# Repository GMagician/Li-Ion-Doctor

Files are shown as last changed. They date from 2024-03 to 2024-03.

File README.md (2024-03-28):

# Lithium battery doctor

**PROOF OF CONCEPT PROJECT**

**:warning::boom: WARNING:LITHIUM BATTERY MAY EASILY EXPLODE OR TAKE FIRE, REPLICATE THIS PROJECT AT YOUR OWN RISK:boom::warning:**

Complete solution for Li Ion batteries

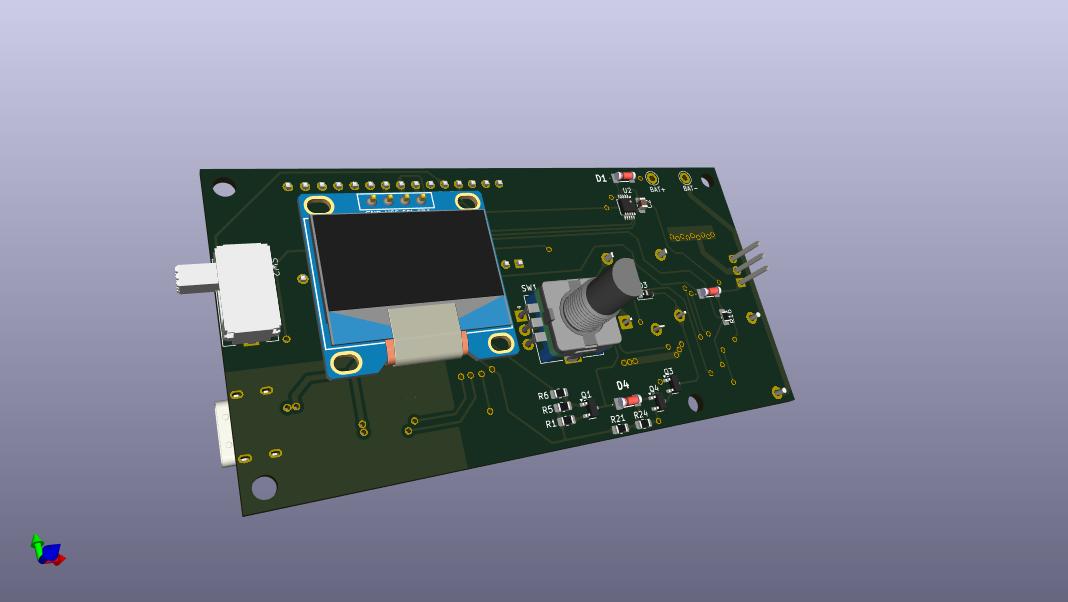
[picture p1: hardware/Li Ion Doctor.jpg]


Features:<br />
  Charge, discharge, amp hours count, test for short or open circuit, weak battery indicator, measure internal resistance.

- Charge:<br />
  TP4056 module (integrated), selectable current ~200/500/1000mA. TP4056 circuit is monitored by Arduino.
- Discharge:<br />
  current up to 2000mA (step 10mA), PWM controlled. Internal resistance is calculated from battery voltage drop under load.
- Capacity:<br />
  Battery gets fully charged, then discharged, mAh on selected current load is counted.
- Recovery:<br />
  Deep discharged battery charge with 100mA current.<br /><br />

This is a revisited project originally developped by Akos Boda in 2022 (https://www.thingiverse.com/thing:5229303).

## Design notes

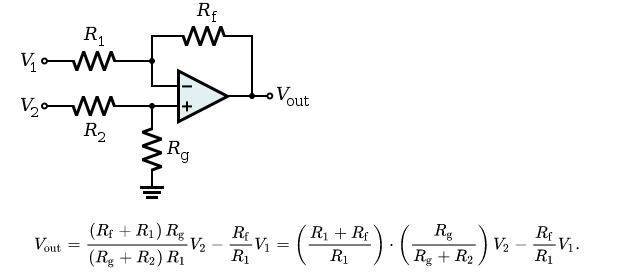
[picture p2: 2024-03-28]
hardware/documents/Differential amplifier + offset.png

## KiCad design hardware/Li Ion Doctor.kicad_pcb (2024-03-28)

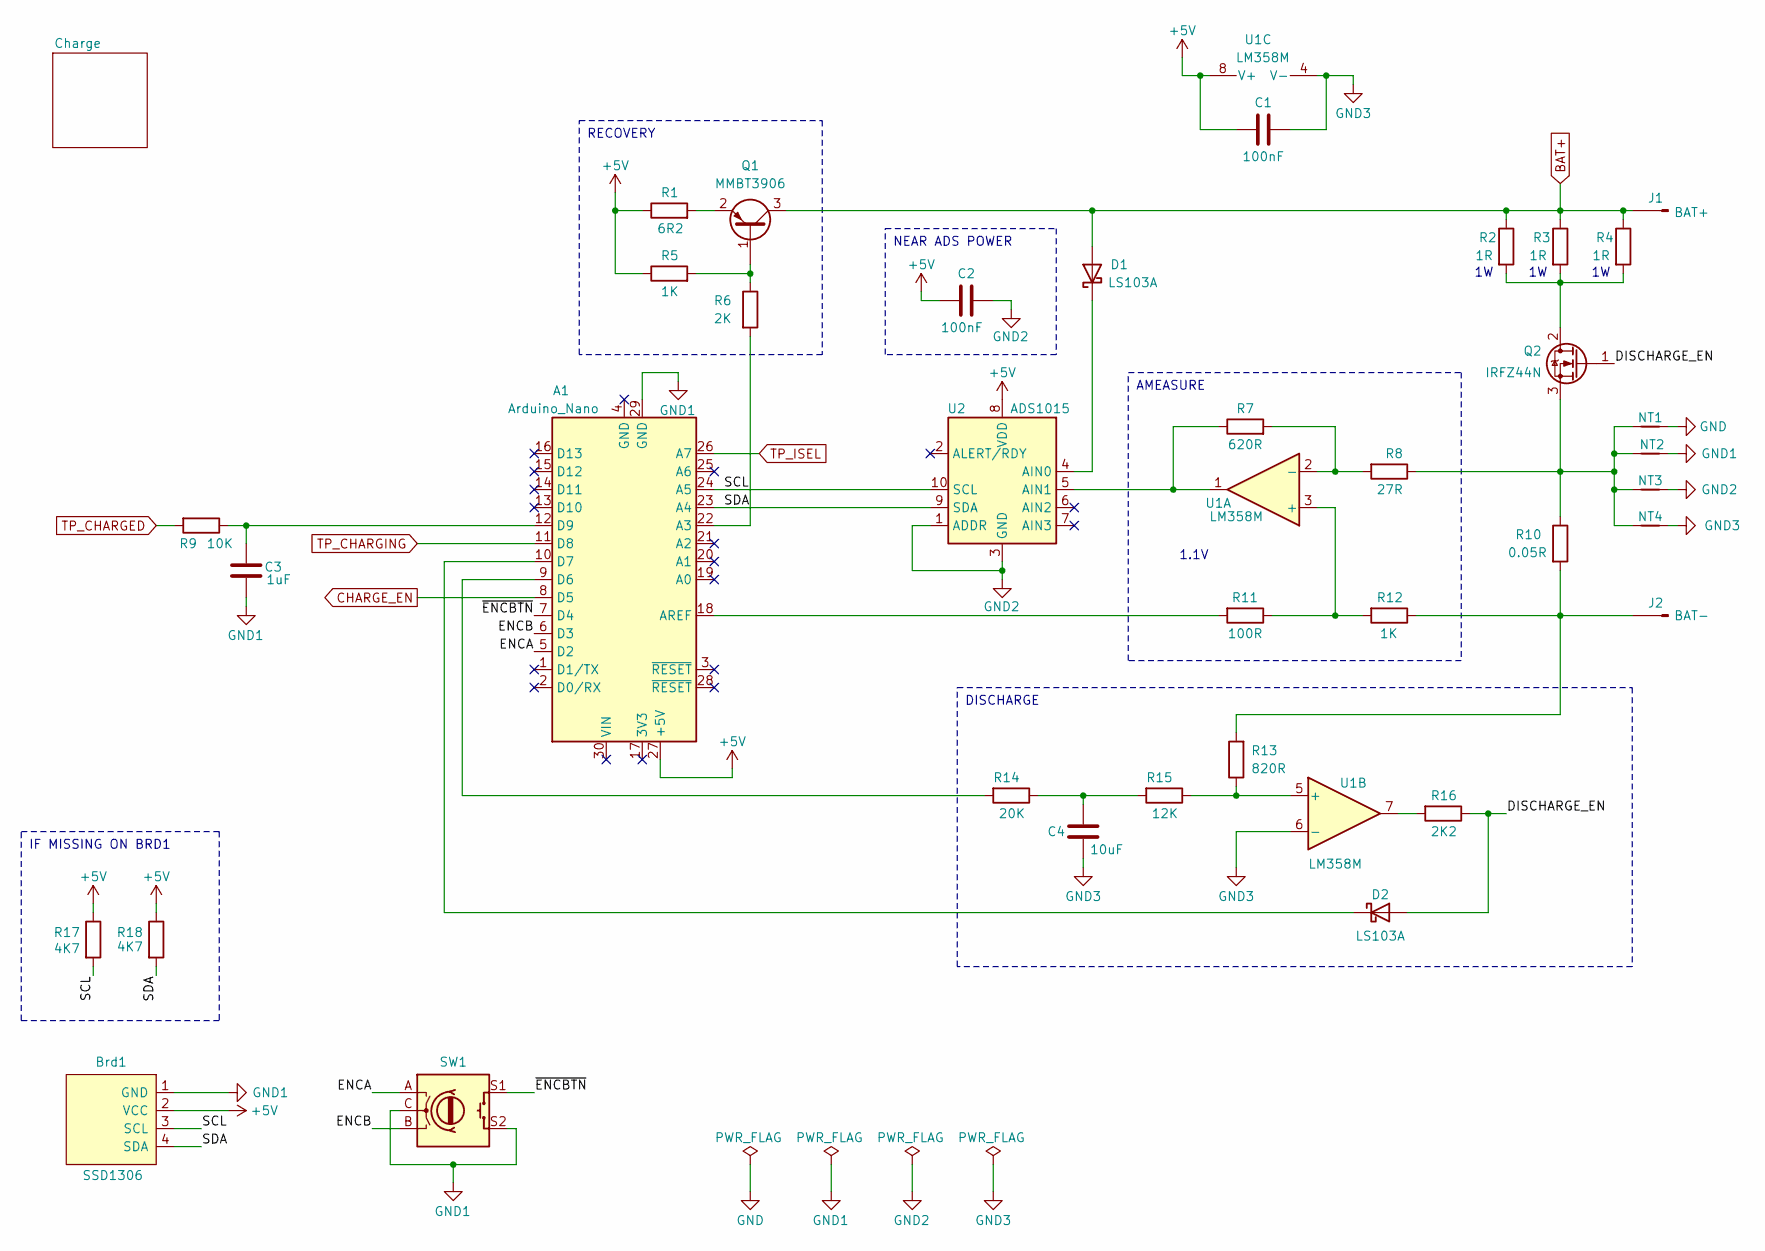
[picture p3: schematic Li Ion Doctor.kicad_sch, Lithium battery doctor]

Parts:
A1: Arduino_Nano
Brd1: SSD1306; SSD1306_OLED_DISPLAY_0.96
C1, C2: 100nF; C_0805_2012Metric_Pad1.18x1.45mm_HandSolder
C3: 1uF; C_0805_2012Metric_Pad1.18x1.45mm_HandSolder
C4: 10uF; C_0805_2012Metric_Pad1.18x1.45mm_HandSolder
D1, D2: LS103A; D_SOD-80
J1: BAT+; Pin_D1.0mm_L10.0mm_LooseFit
J2: BAT-; Pin_D1.0mm_L10.0mm_LooseFit
NT1: NetTie_2; NetTie-2_SMD_Pad2.0mm
NT2, NT3, NT4: NetTie_2; NetTie-2_SMD_Pad0.5mm
Q1: MMBT3906; SOT-23
Q2: IRFZ44N; TO-220-3_Vertical
R1: 6R2; R_0805_2012Metric_Pad1.20x1.40mm_HandSolder
R2, R3, R4: 1R; R_2512_6332Metric_Pad1.40x3.35mm_HandSolder
R5, R12: 1K; R_0805_2012Metric_Pad1.20x1.40mm_HandSolder
R6: 2K; R_0805_2012Metric_Pad1.20x1.40mm_HandSolder
R7: 620R; R_0805_2012Metric_Pad1.20x1.40mm_HandSolder
R8: 27R; R_0805_2012Metric_Pad1.20x1.40mm_HandSolder
R9: 10K; R_0805_2012Metric_Pad1.20x1.40mm_HandSolder
R10: 0.05R; R_Bare_Metal_Element_L18mm_W2.5mm_P15mm
R11: 100R; R_0805_2012Metric_Pad1.20x1.40mm_HandSolder
R13: 820R; R_0805_2012Metric_Pad1.20x1.40mm_HandSolder
R14: 20K; R_0805_2012Metric_Pad1.20x1.40mm_HandSolder
R15: 12K; R_0805_2012Metric_Pad1.20x1.40mm_HandSolder
R16: 2K2; R_0805_2012Metric_Pad1.20x1.40mm_HandSolder
R17, R18: 4K7; R_0805_2012Metric_Pad1.20x1.40mm_HandSolder
SW1: RotaryEncoder_Switch; RotaryEncoder-Switch_Vertical_H15mm
U1: LM358M; SOP-8_3.9x4.9mm_P1.27mm
U2: ADS1015; TSSOP-10_3x3mm_P0.5mm

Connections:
+5V: A1.27 (+5V), Brd1.2 (VCC), C1.1, C2.1, R1.1, R5.1, R17.1, R18.1, U1.8 (V+), U2.8 (VDD); also elsewhere on the board
/DISCHARGE_EN: D2.2 (A), Q2.1 (G), R16.1
/ENCA: A1.5 (D2), SW1.A
/ENCB: A1.6 (D3), SW1.B
/SCL: A1.24 (A5), Brd1.3 (SCL), R17.2, U2.10 (SCL)
/SDA: A1.23 (A4), Brd1.4 (SDA), R18.2, U2.9 (SDA)
/~ENCBTN: A1.7 (D4), SW1.S1
BAT+: D1.2 (A), J1.1, Q1.3 (C), R2.1, R3.1, R4.1; also elsewhere on the board
CHARGE_EN: A1.8 (D5); also elsewhere on the board
GND: NT1.1; also elsewhere on the board
GND1: A1.29 (GND), Brd1.1 (GND), C3.1, NT2.1, SW1.C, SW1.S2; also elsewhere on the board
GND2: C2.2, NT3.1, U2.1 (ADDR), U2.3 (GND)
GND3: C1.2, C4.2, NT4.1, U1.4 (V-), U1.6 (-)
unnamed: A1.22 (A3), R6.2
unnamed: A1.18 (AREF), R11.2
unnamed: A1.9 (D6), R14.2
unnamed: A1.10 (D7), D2.1 (K)
unnamed: A1.12 (D9), C3.2, R9.1
unnamed: C4.1, R14.1, R15.2
unnamed: D1.1 (K), U2.4 (AIN0)
unnamed: J2.1, R10.2, R12.1, R13.2
unnamed: Q1.1 (B), R5.2, R6.1
unnamed: Q1.2 (E), R1.2
unnamed: Q2.2 (D), R2.2, R3.2, R4.2
unnamed: NT1.2, NT2.2, NT3.2, NT4.2, Q2.3 (S), R8.1, R10.1
unnamed: R16.2, U1.7
unnamed: R11.1, R12.2, U1.3 (+)
unnamed: R7.2, R8.2, U1.2 (-)
unnamed: R13.1, R15.1, U1.5 (+)
unnamed: R7.1, U1.1, U2.5 (AIN1)
TP_CHARGED: R9.2; also elsewhere on the board
TP_CHARGING: A1.11 (D8); also elsewhere on the board
TP_ISEL: A1.26 (A7); also elsewhere on the board

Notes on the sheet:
DISCHARGE
RECOVERY
NEAR ADS POWER
AMEASURE
IF MISSING ON BRD1
1.1V

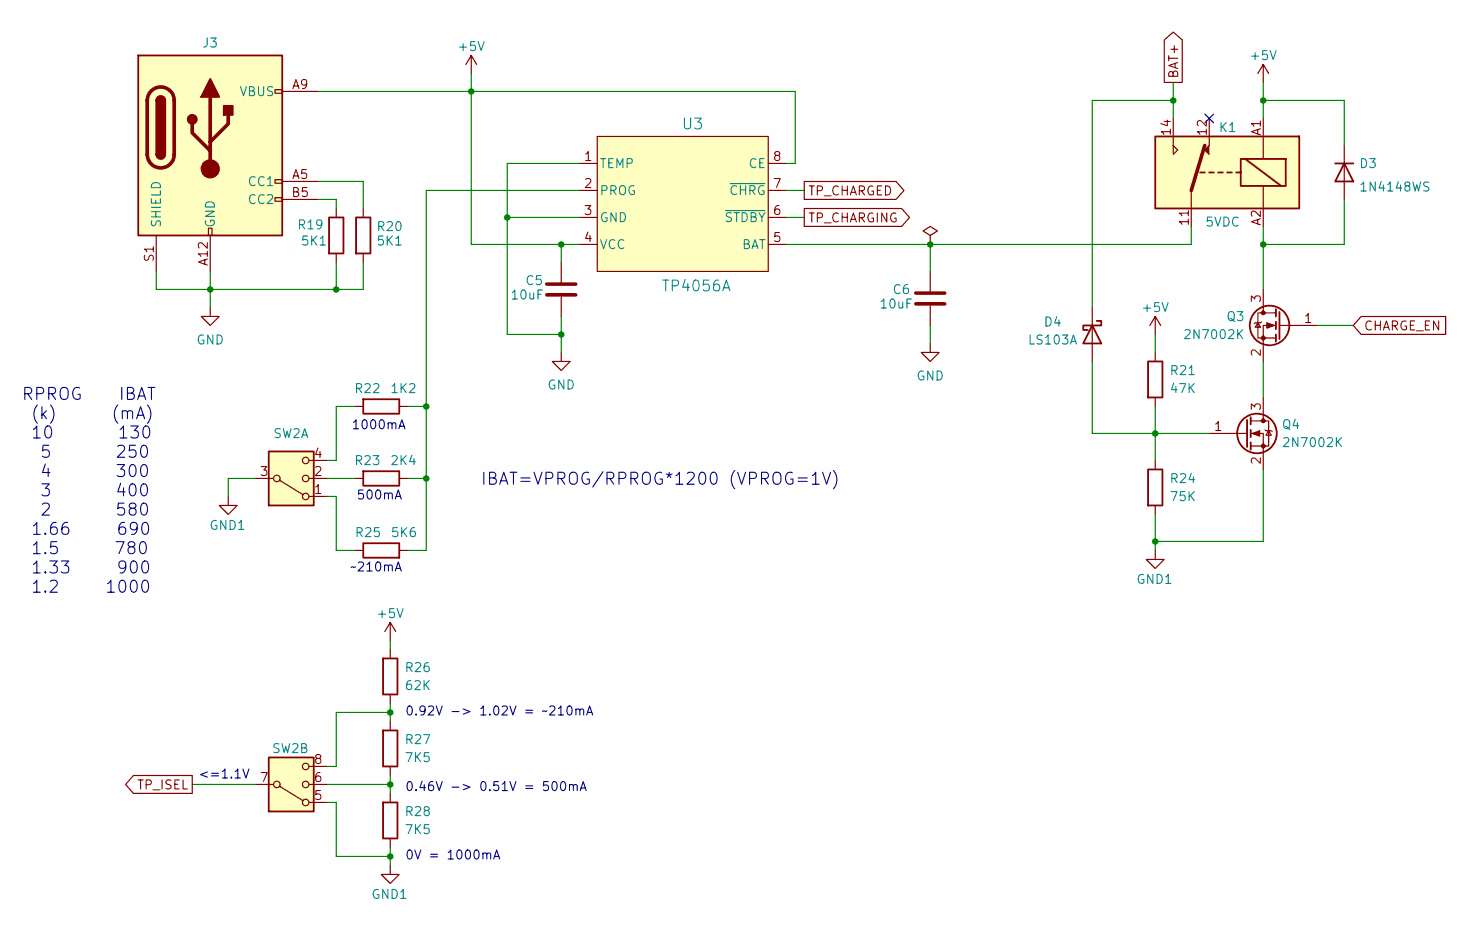
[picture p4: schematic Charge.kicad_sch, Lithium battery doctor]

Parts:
C5, C6: 10uF; C_0805_2012Metric_Pad1.18x1.45mm_HandSolder
D3: 1N4148WS; D_SOD-323_HandSoldering
D4: LS103A; D_SOD-80
J3: USB_C_Receptacle_PowerOnly_6P; USB_C_Receptacle_GCT_USB4125-xx-x_6P_TopMnt_Horizontal
K1: 5VDC; Relay_SPDT_Finder_36.11
Q3, Q4: 2N7002K; SOT-23
R19, R20: 5K1; R_0805_2012Metric_Pad1.20x1.40mm_HandSolder
R21: 47K; R_0805_2012Metric_Pad1.20x1.40mm_HandSolder
R22: 1K2; R_0805_2012Metric_Pad1.20x1.40mm_HandSolder
R23: 2K4; R_0805_2012Metric_Pad1.20x1.40mm_HandSolder
R24: 75K; R_0805_2012Metric_Pad1.20x1.40mm_HandSolder
R25: 5K6; R_0805_2012Metric_Pad1.20x1.40mm_HandSolder
R26: 62K; R_0805_2012Metric_Pad1.20x1.40mm_HandSolder
R27, R28: 7K5; R_0805_2012Metric_Pad1.20x1.40mm_HandSolder
SW2: SW_DP3T; SK23D07VG5
U3: TP4056A; SOP-8_4.2x5.3mm_P1.27mm_EP2.5x3.4mm_ThermalVias

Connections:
+5V: C5.1, D3.1 (K), J3.A9 (VBUS), J3.B9 (VBUS), K1.A1, R21.1, R26.2, U3.4 (VCC), U3.8 (CE); also elsewhere on the board
BAT+: D4.1 (K), K1.14; also elsewhere on the board
CHARGE_EN: Q3.1 (G); also elsewhere on the board
GND: C5.2, C6.1, J3.A12 (GND), J3.B12 (GND), J3.S1 (SHIELD), R19.2, R20.2, U3.1 (TEMP), U3.3 (GND), U3.9 (GND); also elsewhere on the board
GND1: Q4.2 (S), R24.2, R28.1, SW2.3, SW2.5; also elsewhere on the board
unnamed: D3.2 (A), K1.A2, Q3.3 (D)
unnamed: D4.2 (A), Q4.1 (G), R21.2, R24.1
unnamed: J3.A5 (CC1), R20.1
unnamed: J3.B5 (CC2), R19.1
unnamed: Q3.2 (S), Q4.3 (D)
unnamed: R22.2, SW2.4
unnamed: R23.2, SW2.2
unnamed: R25.1, SW2.1
unnamed: R26.1, R27.2, SW2.8
unnamed: R27.1, R28.2, SW2.6
unnamed: C6.2, K1.11, U3.5 (BAT)
unnamed: R22.1, R23.1, R25.2, U3.2 (PROG)
TP_CHARGED: U3.7 (~CHRG); also elsewhere on the board
TP_CHARGING: U3.6 (~STDBY); also elsewhere on the board
TP_ISEL: SW2.7; also elsewhere on the board

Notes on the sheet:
IBAT=VPROG/RPROG*1200 (VPROG=1V)
<=1.1V
500mA
RPROG IBAT (k) (mA) 10 130 5 250 4 300 3 400 2 580 1.66 690 1.5 780 1.33 900 1.2 1000
0.46V -> 0.51V = 500mA
0.92V -> 1.02V = ~210mA
~210mA
0V = 1000mA
1000mA

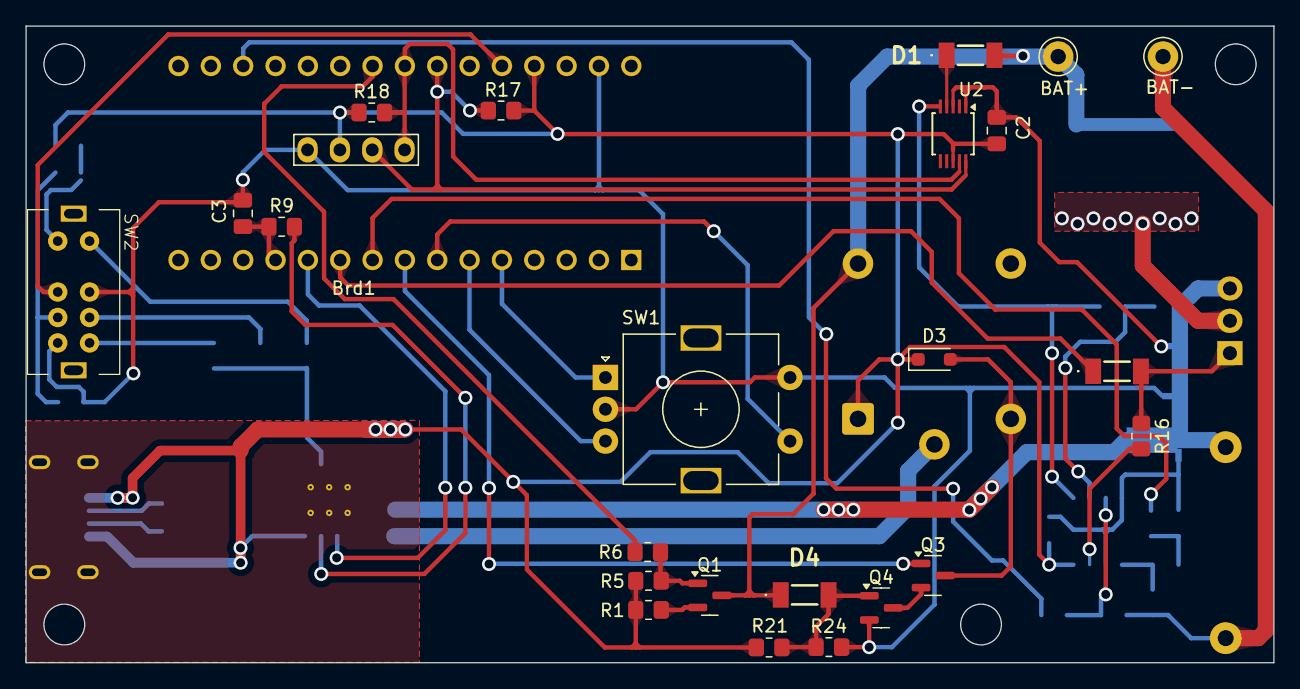
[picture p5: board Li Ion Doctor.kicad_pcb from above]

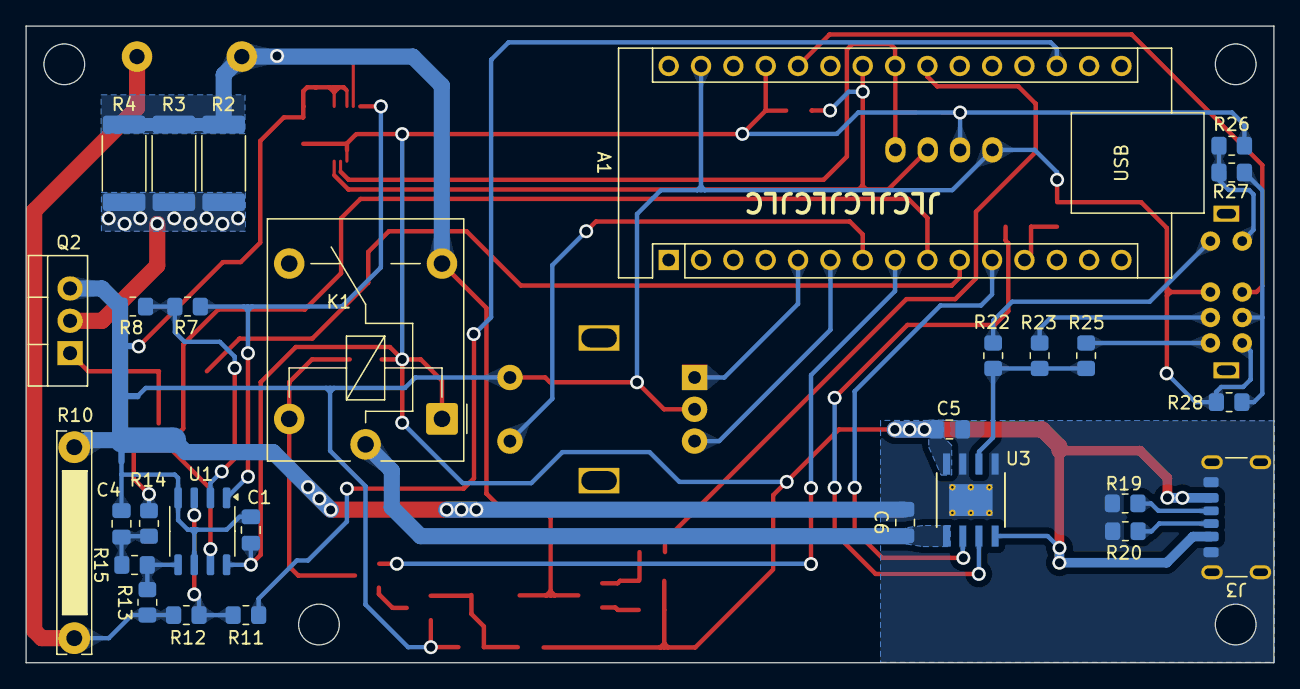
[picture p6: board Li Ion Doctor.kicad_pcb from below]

Board: 2 copper layers, 98.0 x 50.0 mm, 57 parts (33 on the bottom side), 45 nets.

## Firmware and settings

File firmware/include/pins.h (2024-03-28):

#pragma once

// 0/RX
// 1/TX
#define ENCA_PIN                  2
#define ENCB_PIN                  3
#define ENCBTN_PIN                4
#define CHARGE_EN_PIN             5
#define DISCHARGE_PWM_PIN         6
#define DISCHARGE_EN_PIN          7
#define TP_CHARGING_PIN           8
#define TP_CHARGED_PIN            9
// 10
// 11
// 12
// 13
// A0
// A1
// A2
#if HAS_RECOVERY
#define RECOVERY_DIS_PIN          A3
#endif
// SDA                            A4
// SCL                            A5
// A6
#define TP_ISEL_PIN               A7

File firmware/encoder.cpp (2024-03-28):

#include <Arduino.h>
#include "pins.h"

int8_t encoderIncrement;
bool shortPress, longPress;

static uint8_t encPos;


void encoderISR(void) {
  static unsigned long lastEdgeDetectionTime = 0;

  if (digitalRead(ENCA_PIN)) {
    unsigned long time = micros();
    if ((time - lastEdgeDetectionTime) > 250) {
      delayMicroseconds(10);
      encPos += digitalRead(ENCB_PIN) ? +1 : -1;
    }
    lastEdgeDetectionTime = time;
  }
}

void encoderSetup() {
  pinMode(ENCA_PIN, INPUT_PULLUP);
  pinMode(ENCB_PIN, INPUT_PULLUP);
  pinMode(ENCBTN_PIN, INPUT_PULLUP);
  attachInterrupt(digitalPinToInterrupt(ENCA_PIN), encoderISR, RISING);
}

void encoderHandler(void) {
  static uint8_t prevEncPos;

  encoderIncrement = (int8_t)(encPos - prevEncPos);
  prevEncPos += encoderIncrement;

  static bool longpressDetected;
  static unsigned long lastEvent_ms;
  static bool buttonPressed, prevEncButtonReleased;

  const unsigned long ms = millis();
  const bool prevButtonPressed = buttonPressed;

  const bool encButtonReleased = digitalRead(ENCBTN_PIN);
  if (encButtonReleased ^ prevEncButtonReleased)
    lastEvent_ms = ms;
  buttonPressed = !encButtonReleased && (ms - lastEvent_ms >= 50);
  prevEncButtonReleased = encButtonReleased;

  shortPress = !buttonPressed && prevButtonPressed && !longpressDetected;
  if (!buttonPressed || (ms - lastEvent_ms) < 1500)
    longPress = longpressDetected = false;
  else {
    longPress = !longpressDetected;
    longpressDetected = true;
  }
}
